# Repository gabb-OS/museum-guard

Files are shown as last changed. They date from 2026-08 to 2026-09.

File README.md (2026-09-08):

# MuseumGuard

**W3C WoT-based Smart Artwork Protection System**
*Project for the Internet of Things course (A.Y. 2025-2026) — University of Bologna (Unibo)*

---

## Project Description

**MuseumGuard** is a distributed IoT system designed for continuous monitoring and active protection of artworks in museum environments. The system combines environmental monitoring, timely threat detection (accidental impacts and theft attempts), adaptive lighting control, and interoperability based on the **W3C Web of Things (WoT)** standard.

### General Architecture

<div align="center">
  Architetture
</div>

The sensing and actuation nodes never communicate directly with each other: flow orchestration and application logic are handled by the **WoT Controller** and the **Mash-up** application. The `predictive-light` service reads history from InfluxDB and is only queried by the Mash-up to obtain the brightness estimate — it never talks directly to the devices.

---

## System Components

### 1. ESP-SEN — Sensing Node

* **Firmware:** ESP-IDF with FreeRTOS tasks dedicated to acquisition and transmission (`esp/esp-sen/sensing`).
* **Hardware:** ESP32, ambient light sensor (photoresistor on ADC), 3-axis I2C accelerometer (MPU6050), UART GPS module.
* **Features:**
  * Periodic reading of ambient light intensity and triaxial acceleration.
  * **Accidental impact** detection (sudden variation on the Z axis relative to the previous sample).
  * **Theft** detection (sustained displacement on the X axis relative to a baseline, confirmed over several consecutive samples with anti-bounce cooldown).
  * GPS tracking automatically activated after a confirmed theft, until a reset is received.
  * Dynamic runtime configuration of impact/theft thresholds, without recompilation.
* **Protocol:** CoAP (Constrained Application Protocol), UDP port `5683`.
* **Mock:** Python (`esp/esp-sen/mockup/esp_sen_mock.py`), same CoAP interface as the real firmware.

### 2. ESP-ACT — Actuation Node

* **Firmware:** ESP-IDF with FreeRTOS tasks for LED management and HTTP endpoints (`esp/esp-act/actuating`).
* **Hardware:** ESP32, PWM LED (artwork illumination, dimmable via `ledc`), dedicated digital LED for impact/theft.
* **Features:**
  * Adaptive control of artwork illumination via PWM dimming (0–100%).
  * **Impact signaling:** alarm LED blinks for 20 seconds (software timer), interruptible by a theft event.
  * **Theft signaling:** alarm LED turns on permanently until manually reset.
* **Protocol:** HTTP, port `80` on the real device (exposed as `8081` on the mock via Docker).
* **Mock:** Node.js (`esp/esp-act/mockup/server.js`, `mockup-act.js`), same HTTP interface as the real firmware.

### 3. WoT Controller (PC)

Node.js application (`wot-controller/`) that abstracts the two physical devices, exposing them as standardized **W3C WoT Things** via `@node-wot`, reachable at `http://localhost:8080`:

* **`sensor` Thing** (`/sensor`) — exposes ESP-SEN:
  * *Properties:* `ambientLight`, `accelerometer` (`{ax, ay, az}`), `thresholds` (`{impact, theft_displacement}`) — all observable.
  * *Actions:* `setImpactThreshold`, `setTheftThreshold`, `resetTracking`.
  * *Events:* `alarmEvent` — notifies `impact` / `theft` / `position`.
* **`actuator` Thing** (`/actuator`) — exposes ESP-ACT:
  * *Properties:* `artworkLedBrightness`, `alarmLightState` (`IDLE`/`IMPACT`/`THEFT`) — observable.
  * *Actions:* `regulateBrightness`, `triggerImpactBlink`, `triggerTheftAlarm`, `resetAlarmLight`.

The adapters towards the physical devices (CoAP for the sensor, HTTP for the actuator) live in `wot-controller/src/adapters/`.

### 4. Mash-up Application (PC)

Represents the logical core of the system (`mashup-app/`):

* Consumes the Things exposed by the WoT Controller (`clients/wotConsumer.js`).
* Performs periodic req/res polling of sensor + actuator and persists telemetry, events, and thresholds to **InfluxDB** (`logic/telemetryPoller.js`, `services/influxService.js`).
* Subscribes to the `alarmEvent` event in pub/sub mode and reacts to impacts/thefts by triggering the corresponding actuators and sending Telegram notifications (`logic/alarmHandler.js`).
* Queries the `predictive-light` service for the target brightness, with an explicit reactive fallback in case of error/timeout (`services/predictiveLightService.js`).
* Exposes a small internal REST API (`api/server.js`, port `3001`) used by Grafana's form panels for actions such as alarm reset and threshold updates, without Grafana needing to talk directly to the WoT Controller.

### 5. Predictive Lighting Service

Standalone Python/FastAPI microservice (`predictive-light/App.py`), containerized separately, based on a **"refit-once, serve-many"** architecture: the expensive ARIMA re-fit and the serving of predictions to the Mash-up are decoupled, so the service can respond to `/predict` with fine granularity without having to refit the model on every call.

* Every `PREDICT_INTERVAL_S` seconds (default `60`) it re-fits an **ARIMA** model (`pmdarima`) on the rolling window of `ambient_light` read from InfluxDB (`HISTORY_WINDOW_S` seconds), and in a single pass generates an **array of future forecasts** (`forecast_cache`), one every `FORECAST_STEP_S` seconds (default `1`), covering the interval up to the next refit.
* `GET /predict` **never re-fits** the model: it only computes how much time has elapsed since the last refit and returns the cache point closest to "now" — near-zero computational cost, regardless of how often the Mash-up polls the endpoint.
* Applies an **adaptive bias correction**: it maintains an EMA (`EMA_ALPHA`) over past forecast errors. Reconciliation still operates on a single reference point per refit cycle, selected at `PREDICTION_HORIZON_S` seconds after the fit (dedicated `prediction_error` measurement); that point is now extracted from the cache instead of being the sole output of the fit, but the reconciliation logic itself is unchanged.
* Exposes `GET /predict` → `{"predicted_ambient_light": <float>}` (Photoresistor target, predicted ambient light) and `GET /health` for diagnostics (also includes `forecast_cache_points` and `forecast_cache_age_s`); returns `503` until a valid fit is available, so the Mash-up falls back to the reactive rule.
* Writes both the forecasts (`predicted_light`) and the reconciliation errors (`prediction_error`) to InfluxDB, both viewable in Grafana and tagged with `system=museumguard`, consistent with the rest of the measurements written by the Mash-up.

### 6. Data Storage & Visualization

* **InfluxDB 2.7:** Time-series database for telemetry (`ambient_light`, `acceleration`, `actuator_state`), events (`impact_event`, `theft_event`, `position`), thresholds (`device_thresholds`), and predictive data (`predicted_light`, `prediction_error`). Bucket retention set via `INFLUXDB_RETENTION` (default `30d`) by `influxdb/init/01-setup.sh` on first startup.
* **Grafana:** `MuseumGuard` dashboard automatically provisioned (`grafana/dashboards/museumguard.json`) with environmental charts, impact/theft event tables, GPS map, actuator state, predicted-vs-actual light comparison, prediction error, and form panels (`volkovlabs-form-panel` plugin) for alarm reset and threshold configuration — the latter call the Mash-up API (`http://localhost:3001/api/...`) directly.

### 7. Telegram Alert Bot

`services/telegramService.js` module in the Mash-up: sends fire-and-forget text notifications to the configured chat whenever `alarmHandler.js` receives an `impact` or `theft` event. If `TELEGRAM_BOT_TOKEN`/`TELEGRAM_BOT_CHAT_ID` are not set, the bot remains disabled without blocking the rest of the system.

---

## Implemented Bonus Features

* **Configurable Detection Thresholds:** runtime updates of the impact (`thresholds/impact`) and theft (`thresholds/theft`) thresholds through the WoT Controller, without firmware recompilation, with range validated on the firmware side (`THRESHOLD_MIN`–`THRESHOLD_MAX`, 0.05–5.00 g).
* **Predictive Lighting Control:** ARIMA model with adaptive bias correction and a "refit-once, serve-many" architecture (periodic refit every `PREDICT_INTERVAL_S`, predictions served with `FORECAST_STEP_S` granularity from an in-memory cache) that estimates ambient light over the next `PREDICTION_HORIZON_S` seconds and proactively regulates the PWM LED, with automatic reactive fallback if the predictive service is unavailable.
* **Telegram Alert Bot:** instant notifications in case of emergency (impact/theft).
* **GPS:** To make the prototype more realistic, it was decided to add a GPS to provide the artwork's location in the event of theft. 

---

## Repository Structure

```text
museum-guard/
├── esp/
│   ├── esp-act/
│   │   ├── actuating/         # ESP-IDF firmware (Actuation Node)
│   │   │   └── main/          # main.c, networkConnect.c, shared.h
│   │   └── mockup/            # Node.js mock (server.js, mockup-act.js)
│   └── esp-sen/
│       ├── sensing/           # ESP-IDF firmware (Sensing Node)
│       │   └── main/
│       │       └── mylib/     # accelerometer, gps, wifi, coap_server
│       └── mockup/            # Python mock (esp_sen_mock.py)
├── wot-controller/            # W3C WoT Controller (Node.js / node-wot)
│   ├── src/
│   │   ├── adapters/          # espAct-adapter.js, espSen-adapter.js
│   │   ├── coap/              # coap-client.js
│   │   ├── things/            # espActThing.js, espSenThing.js
│   │   └── index.js
│   └── mockup/                # test scripts (testActThing.js)
├── mashup-app/                # Mash-up Application (Node.js)
│   └── src/
│       ├── api/                # server.js — internal REST API (port 3001)
│       ├── clients/             # wotConsumer.js
│       ├── logic/               # telemetryPoller.js, alarmHandler.js
│       ├── services/            # influxService.js, predictiveLightService.js, telegramService.js
│       ├── config.js
│       └── index.js
├── predictive-light/           # Predictive service (Python/FastAPI)
│   ├── App.py
│   └── requirements.txt
├── grafana/                    # Automatic provisioning and dashboard
│   ├── datasources/             # influxdb.yml
│   └── dashboards/              # dashboard.yml, museumguard.json
├── influxdb/
│   └── init/                   # 01-setup.sh — bucket retention
├── models/                     # STL files for 3D-printed cases
├── schematics/                 # Fritzing circuit diagrams (.fzz/.png)
├── docker-compose.yml           # Full environment orchestration
├── env.example                  # Environment variables template
├── LICENSE
└── README.md
```

---

## Interface Specification

### ESP-SEN (CoAP — port `5683/udp`)

| Resource | Method | Body / Payload | Description |
| --- | --- | --- | --- |
| `/light` | `GET` | — | Detected ambient light percentage (0–100) |
| `/accel` | `GET` | — | Average acceleration JSON `{"ax": float, "ay": float, "az": float}` |
| `/events` | `GET` (observable) | — | Latest event (`impact` / `theft` / `position`); notifies observers via CoAP Observe |
| `/thresholds` | `GET` | — | Current thresholds `{"impact": float, "theft_displacement": float}` |
| `/thresholds/impact` | `PUT` | text, numeric value (0.05–5.00) | Updates the impact threshold; `4.00 BAD_REQUEST` if out of range or payload invalid |
| `/thresholds/theft` | `PUT` | text, numeric value (0.05–5.00) | Updates the theft displacement threshold; same validation |
| `/reset_alarm` | `PUT` | — | Recalibrates the accelerometer baseline and stops GPS tracking |

### ESP-ACT (HTTP — port `80` on the real device / `8081` on the Docker mock)

| Endpoint | Method | Body | Description |
| --- | --- | --- | --- |
| `/` | `GET` | — | Basic health check |
| `/state` | `GET` | — | Current state `{"id", "brightness", "alarmState"}` |
| `/ambientlight` | `POST` | `{"brightness": 0-100}` | Sets the PWM brightness of the artwork LED |
| `/impact` | `POST` | — | Triggers impact signaling (20s blink) |
| `/theft` | `POST` | — | Triggers theft signaling (LED steady on) |
| `/reset` | `POST` | — | Resets the alarm state to `IDLE` |

### Internal Mash-up API (HTTP — port `3001`)

Used by Grafana (form panels) so they don't need to talk directly to the WoT Controller.

| Endpoint | Method | Body | Description |
| --- | --- | --- | --- |
| `/api/health` | `GET` | — | Health check |
| `/api/resetalarm` | `POST` | — | Invokes `resetAlarmLight` on the actuator |
| `/api/thresholds` | `GET` | — | Reads current thresholds from the sensor (pre-fills Grafana forms) |
| `/api/thresholds/impact` | `POST` | `{"value": number}` | Sets the impact threshold via the `sensor` Thing |
| `/api/thresholds/theft` | `POST` | `{"value": number}` | Sets the theft threshold via the `sensor` Thing |

### WoT Controller — Thing Descriptions (HTTP — port `8080`)

| Resource | Description |
| --- | --- |
| `/sensor` | Thing Description of the sensing node (properties, actions, events listed above) |
| `/actuator` | Thing Description of the actuation node |

### Predictive Light Service (HTTP — port `8000`, reachable only within the internal Docker network)

| Endpoint | Method | Description |
| --- | --- | --- |
| `/predict` | `GET` | `{"brightness": <float>}`, read from the forecast cache; `503` if no fit is available yet |
| `/health` | `GET` | Diagnostics: last fit, current EMA bias, forecast cache size/age |

---

## Getting Started

### Prerequisites

* **Docker** and **Docker Compose**
* **Node.js** (v18+) and **Python** (3.11+) *(only for standalone execution of the mocks, without Docker)*
* **ESP-IDF v5.x** *(only for deployment on real hardware)*
* Telegram Bot Token (obtainable via [@BotFather](https://t.me/BotFather))

---

### Running with Docker

The system supports several startup modes, selectable via **Docker Compose profiles** and an environment variables file.

#### Configuration

The repository only versions the `env.example` template; copy it according to the scenario you need (note: these names do **not** have a leading dot, unlike the more common `.env.*` convention):

```bash
cp env.example env.mock    # to work without hardware (both mocked)
cp env.example env.real    # to work with both real ESP32s
```

In the real-hardware scenario, set the device IP addresses on your LAN in `env.real`:

```env
ESP_SEN_ADDRESS=192.168.x.x
ESP_ACT_ADDRESS=192.168.x.x
```

> ⚠️ The PC running `docker compose` must be on the same WiFi network as the ESP32s — the WoT Controller reaches them as an outgoing CoAP/HTTP client, no port needs to be exposed on the ESP32 side.

For **mixed** scenarios (one real node, the other mocked), the only difference is that in `ESP_SEN_ADDRESS`/`ESP_ACT_ADDRESS` you put the mock container name for the node you want to simulate, and the real IP for the other:

```env
# example: ESP-SEN real device connected, ESP-ACT still mocked
ESP_SEN_ADDRESS=192.168.1.42
ESP_ACT_ADDRESS=esp-act-mock
```

#### Main Environment Variables

| Variable | Default | Description |
| --- | --- | --- |
| `INFLUXDB_USERNAME` / `INFLUXDB_PASSWORD` | — | InfluxDB admin credentials (initial setup) |
| `INFLUXDB_ORG` / `INFLUXDB_BUCKET` / `INFLUXDB_TOKEN` | — | InfluxDB organization, bucket, and token, shared by all services |
| `INFLUXDB_RETENTION` | `30d` | Bucket retention, applied by `01-setup.sh` |
| `GRAFANA_USER` / `GRAFANA_PASSWORD` | — | Grafana admin credentials |
| `TELEGRAM_BOT_TOKEN` / `TELEGRAM_BOT_CHAT_ID` | — | Telegram bot; if absent, alerts remain disabled |
| `ESP_SEN_ADDRESS` / `ESP_ACT_ADDRESS` | `esp-sen-mock` / `esp-act-mock` | Node hosts (mock or real IP on the LAN) |
| `COAP_PORT` / `HTTP_PORT` | — | Ports used by the WoT Controller to reach ESP-SEN/ESP-ACT |
| `TELEMETRY_POLL_MS` | `5000` | Req/res polling interval of sensor+actuator in the Mash-up |
| `MASHUP_SERVER_API_PORT` | `3001` | Port of the Mash-up's internal REST API |
| `PREDICTIVE_LIGHT_URL` | `http://predictive-light:8000` | URL of the predictive service, as seen by the Mash-up |
| `PREDICTIVE_LIGHT_TIMEOUT_MS` | `3000` | Timeout for the call to `predictive-light` before falling back to the reactive rule |
| `PREDICT_INTERVAL_S` | `60` | How often (seconds) `predictive-light` re-fits the ARIMA model and regenerates the forecast cache ("refit-once, serve-many") |
| `FORECAST_STEP_S` | `1` | Granularity (in seconds) of the forecasts served from the cache between one refit and the next; ideally aligned with `TELEMETRY_POLL_MS` |
| `PREDICTION_HORIZON_S` | `30` | Forecast horizon used for reconciliation/EMA bias (seconds into the future relative to the fit) |
| `HISTORY_WINDOW_S` | `600` | Rolling history window used for the ARIMA fit |
| `EMA_ALPHA` | `0.3` | EMA weight for the adaptive bias correction |

#### Clone and Run

```bash
git clone https://github.com/your-username/museum-guard.git
cd museum-guard
```

**With both mocks (test environment, no hardware):**
```bash
docker compose --env-file env.mock --profile mock up -d
```

**With a single mocked node** (the other real, IP address set in `env.mock`/`env.real`):
```bash
docker compose --env-file env.mock --profile mock-sen up -d   # only ESP-SEN mocked
docker compose --env-file env.mock --profile mock-act up -d   # only ESP-ACT mocked
```

**With real hardware connected (both nodes):**
```bash
docker compose --env-file env.real up -d
```
(here the mock containers do *not* start, even though they remain defined in `docker-compose.yml`, because they don't belong to the default profile)

If you'd rather not type `--env-file` every time, you can copy the chosen file to `.env` (which Compose loads automatically):
```bash
cp env.mock .env   # or env.real, depending on the scenario
docker compose --profile mock up -d          # both mocked
docker compose --profile mock-sen up -d      # only sensing mocked
docker compose up -d                         # real hardware, no profile
```

#### Check Running Services

* **Grafana:** [http://localhost:3000](http://localhost:3000) — dashboard and InfluxDB datasource already provisioned
* **InfluxDB:** [http://localhost:8086](http://localhost:8086)
* **WoT Controller:** [http://localhost:8080](http://localhost:8080) — Thing Descriptions of the exposed nodes at `/sensor` and `/actuator`
* **Mash-up API:** [http://localhost:3001/api/health](http://localhost:3001/api/health)
* **Predictive Light:** reachable only within the internal Docker network (`http://predictive-light:8000`), not exposed on the host
* **ESP-SEN Mock** *(`mock` or `mock-sen` profiles)*: `coap://localhost:5683`
* **ESP-ACT Mock** *(`mock` or `mock-act` profiles)*: [http://localhost:8081](http://localhost:8081)

#### Stopping the Services

```bash
docker compose down
```

### Standalone Execution of the Mocks (without Docker)

Useful for developing or debugging a single mock in isolation:

```bash
# Sensing mock (ESP-SEN) — Python
cd esp/esp-sen/mockup
pip install -r requirements.txt
python esp_sen_mock.py

# Actuation mock (ESP-ACT) — Node.js
cd esp/esp-act/mockup
npm install
node server.js
```

---

## License

This project is distributed under the **MIT** license. See the [LICENSE](./LICENSE) file for details.

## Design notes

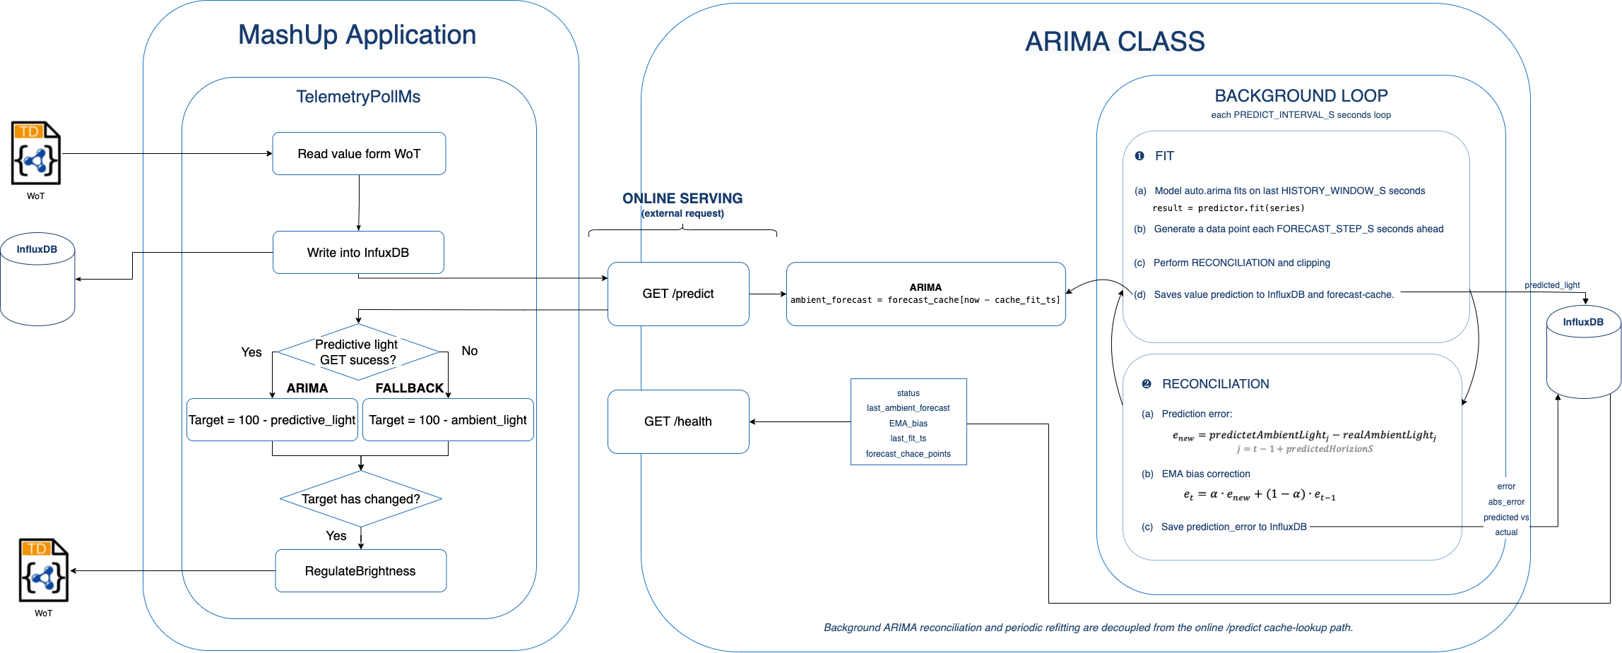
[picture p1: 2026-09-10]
schematics/predict_light.png

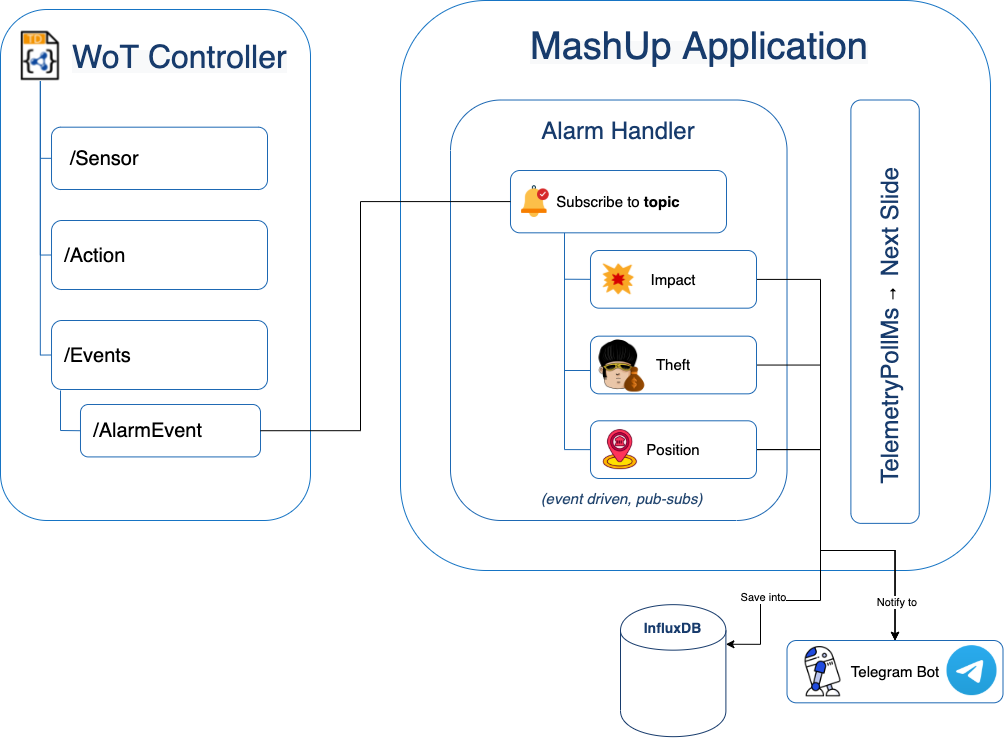
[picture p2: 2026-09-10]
schematics/alarmHandler.png

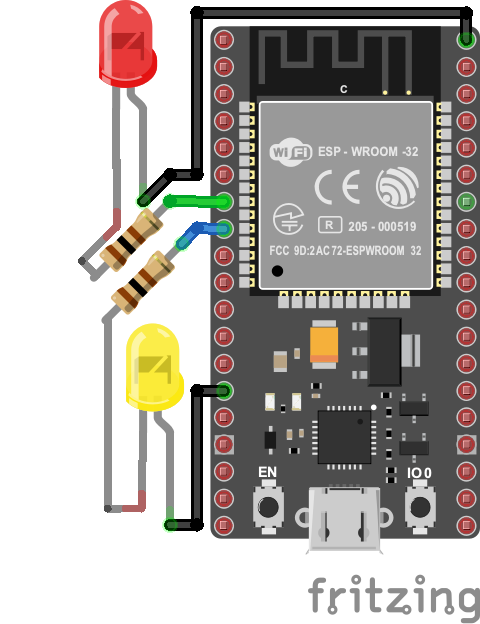
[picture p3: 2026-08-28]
schematics/actuating.png

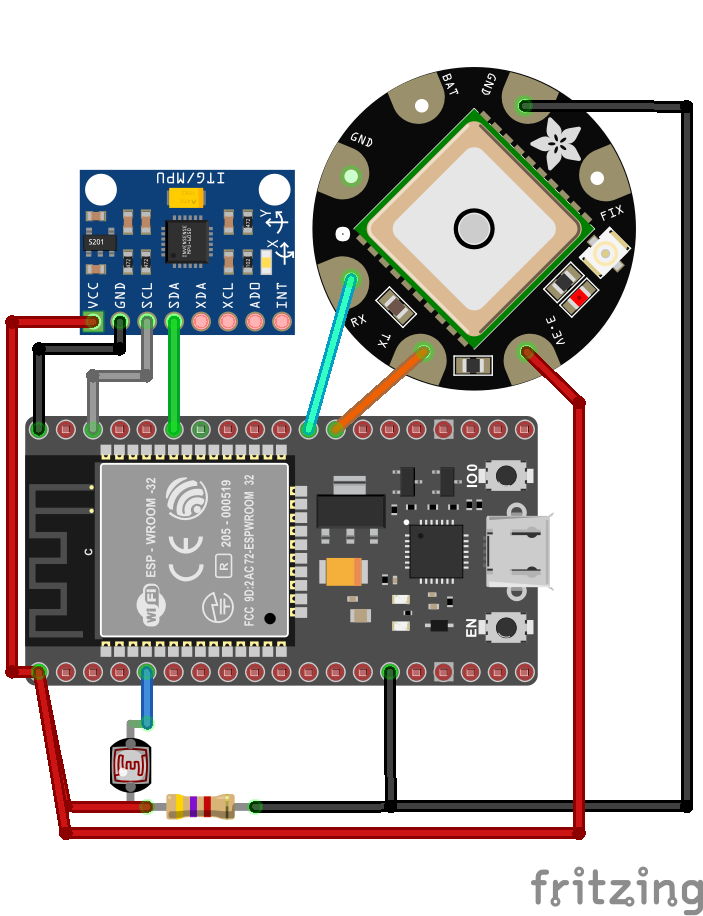
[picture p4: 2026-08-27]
schematics/sensing.png

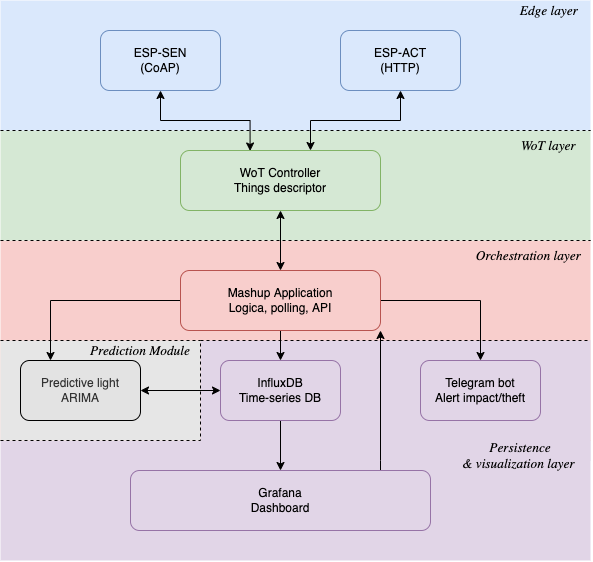
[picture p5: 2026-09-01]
schematics/Architetture.png

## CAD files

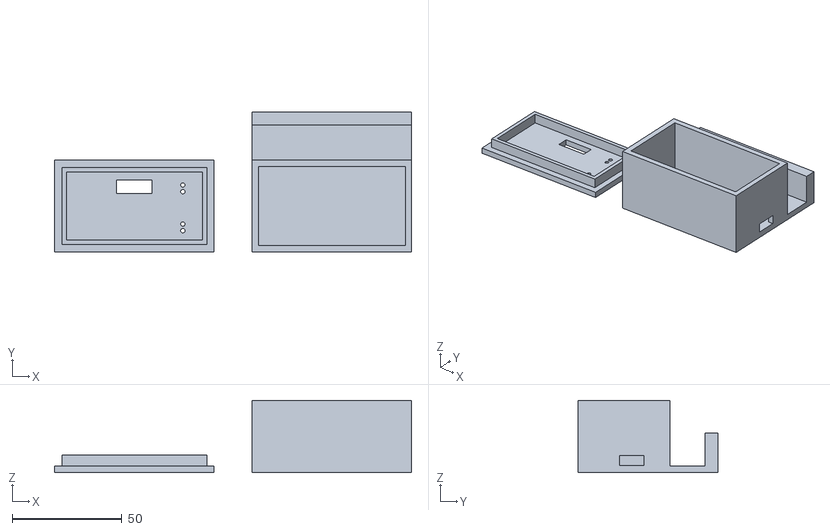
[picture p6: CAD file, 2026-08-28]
models/case actuating.stl
162.7 x 63.8 x 33.0

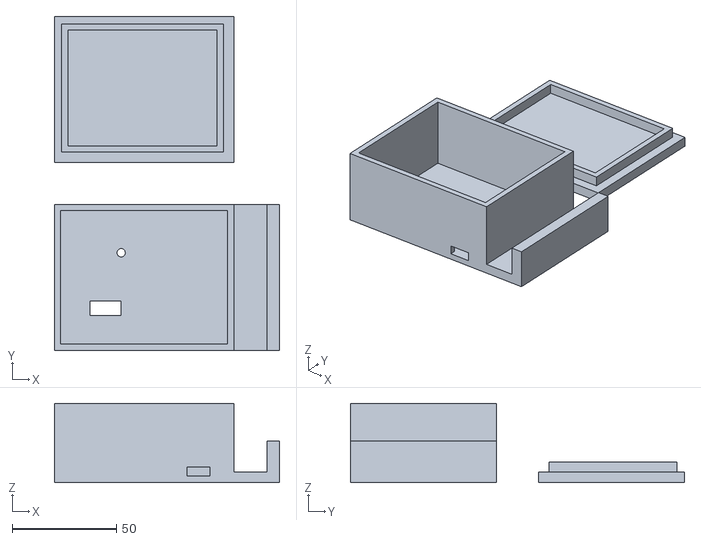
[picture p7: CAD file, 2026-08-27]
models/case sensing.stl
108.0 x 160.0 x 38.0

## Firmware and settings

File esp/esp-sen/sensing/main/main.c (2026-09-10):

#include <stdio.h>
#include <stdlib.h>
#include <string.h>
#include <math.h>
#include <coap3/coap.h>
#include "freertos/FreeRTOS.h"
#include "freertos/task.h"
#include <stdint.h>
#include "driver/gpio.h"
#include "esp_log.h"
#include "esp_timer.h"
#include "driver/adc.h"
#include "nvs_flash.h"
#include "mylib/accelerometer.h"
#include "mylib/wifi.h"
#include "mylib/coap_server.h"
#include "mylib/gps.h"

// Wifi 
#define WIFI_SSID          CONFIG_WIFI_SSID
#define WIFI_PASSWORD      CONFIG_WIFI_PASSWORD
// GPS
#define GPS_UART_NUM   UART_NUM_1
#define GPS_TX_PIN     GPIO_NUM_17
#define GPS_RX_PIN     GPIO_NUM_16
#define GPS_BAUD_RATE  9600
#define GPS_PING_INTERVAL_MS      5000   // during tracking (theft)
#define GPS_WARMUP_INTERVAL_MS    2000   // cold start, before the first fix
#define GPS_IDLE_INTERVAL_MS      10000  // idle, after the first fix, no theft

// global alert state
static bool g_tracking_active = false;
static SemaphoreHandle_t g_tracking_mutex;

// mutex dedicated to the theft detection state (baseline + counter)
static SemaphoreHandle_t g_theft_mutex;

// photoresistor stuff
#define LIGHT_SENS ADC1_CHANNEL_6
#define LIGHT_RAW_MIN             0
#define LIGHT_RAW_MAX             4095
static float g_light_percent = 0.0f;
static int g_light_raw = 0;
SemaphoreHandle_t g_light_mutex;

// accelerometer stuff
#define SDA_ACC_SENS GPIO_NUM_21
#define SCL_ACC_SENS GPIO_NUM_22
#define I2C_MASTER_NUM      I2C_NUM_0
#define I2C_MASTER_FREQ_HZ  400000
static float sum_ax = 0, sum_ay = 0, sum_az = 0;
static int sample_count = 0;
static SemaphoreHandle_t g_accel_mutex;
static float g_avg_ax = 0, g_avg_ay = 0, g_avg_az = 0; 

// runtime configurable thresholds
static float g_impact_threshold = 0.4f;
static float g_theft_displacement_threshold = 0.25f;
static SemaphoreHandle_t g_threshold_mutex;
#define THRESHOLD_MIN 0.05f
#define THRESHOLD_MAX 5.00f

// THEFT
#define THEFT_CONFIRM_SAMPLES        6
static float baseline_ax = 0;
static bool  baseline_set = false;
static int   theft_counter = 0;
#define THEFT_COOLDOWN_MS 3000
static int64_t last_theft_trigger_us = 0;

void read_light_sensor(void *pvParameters) {
    while (1) {
        int raw = adc1_get_raw(LIGHT_SENS);
        float percent;
        if (raw <= LIGHT_RAW_MIN) {
            percent = 0.0f;
        } else if (raw >= LIGHT_RAW_MAX) {
            percent = 100.0f;
        } else {
            percent = (float)(raw - LIGHT_RAW_MIN) / (LIGHT_RAW_MAX - LIGHT_RAW_MIN) * 100.0f;
        }

        xSemaphoreTake(g_light_mutex, portMAX_DELAY);
        g_light_raw = raw;
        g_light_percent = percent;
        xSemaphoreGive(g_light_mutex);
        
        xSemaphoreTake(g_tracking_mutex, portMAX_DELAY);
        bool is_tracking = g_tracking_active;
        xSemaphoreGive(g_tracking_mutex);
        ESP_LOGI("STATUS", "Luce RAW: %d | Percentuale: %.1f%% | Stato: %s", raw, percent, is_tracking ? "TRACKING" : "IDLE");
        
        vTaskDelay(pdMS_TO_TICKS(1000));
    }
}

void calibrate_theft_baseline(float ax) {
    xSemaphoreTake(g_theft_mutex, portMAX_DELAY);
    baseline_ax = ax;
    baseline_set = true;
    xSemaphoreGive(g_theft_mutex);
}

void read_accelerometer_sensor(void *pvParameters) {
    float ax = 0, ay = 0, az = 0;
    float last_ax = 0, last_ay = 0, last_az = 0;
    float diff_x, diff_y, diff_z;
    read_accel(&last_ax, &last_ay, &last_az);
    calibrate_theft_baseline(last_ax); 
    
    while (1) {
        if (read_accel(&ax, &ay, &az)) {
            diff_z = az - last_az;

            // --- IMPACT ---
            xSemaphoreTake(g_threshold_mutex, portMAX_DELAY);
            float impact_th = g_impact_threshold;
            xSemaphoreGive(g_threshold_mutex);
            
            if (fabs(diff_z) > impact_th) {
                char event_buf[64];
                int elen = snprintf(event_buf, sizeof(event_buf),
                                    "{\"type\":\"impact\",\"axis\":\"z\",\"value\":%.3f}", diff_z);
                coap_push_event(event_buf, elen);
                ESP_LOGW("EVENT", "IMPATTO rilevato (diff_z: %.3f)", diff_z);
            }
            
            // --- THEFT ---
            xSemaphoreTake(g_threshold_mutex, portMAX_DELAY);
            float theft_th = g_theft_displacement_threshold;
            xSemaphoreGive(g_threshold_mutex);
            
            xSemaphoreTake(g_theft_mutex, portMAX_DELAY);
            if (baseline_set) {
                float displacement = ax - baseline_ax;
                
                if (fabs(displacement) > theft_th) {
                    theft_counter += 2;
                    if (theft_counter > 50) theft_counter = 50;
                } else if (fabs(displacement) < (theft_th * 0.4f)) {
                    theft_counter -= 1;
                    if (theft_counter < 0) theft_counter = 0;
                }
                
                if (theft_counter >= THEFT_CONFIRM_SAMPLES) {
                    int64_t now_us = esp_timer_get_time();
                    if (now_us - last_theft_trigger_us > (int64_t)THEFT_COOLDOWN_MS * 1000) {
                        char event_buf[64];
                        int elen = snprintf(event_buf, sizeof(event_buf),
                                            "{\"type\":\"theft\",\"axis\":\"x\",\"value\":%.3f}", displacement);
                        coap_push_event(event_buf, elen);
                        
                        xSemaphoreTake(g_tracking_mutex, portMAX_DELAY);
                        g_tracking_active = true;
                        xSemaphoreGive(g_tracking_mutex);
                        last_theft_trigger_us = now_us;
                        
                        ESP_LOGE("EVENT", "FURTO confermato (spostamento: %.3f)", displacement);
                    }
                    theft_counter = 0;
                }
            }
            xSemaphoreGive(g_theft_mutex);
            
            last_ax = ax;
            last_ay = ay;
            last_az = az;
            
            xSemaphoreTake(g_accel_mutex, portMAX_DELAY);
            sum_ax += ax;
            sum_ay += ay;
            sum_az += az;
            sample_count++;
            xSemaphoreGive(g_accel_mutex);
        }
        vTaskDelay(pdMS_TO_TICKS(10));
    }
}

void accel_avg_task(void *pvParameters) {
    int print_counter = 0;
    while (1) {
        xSemaphoreTake(g_accel_mutex, portMAX_DELAY);
        if (sample_count > 0) {
            g_avg_ax = sum_ax / sample_count;
            g_avg_ay = sum_ay / sample_count;
            g_avg_az = sum_az / sample_count;
        }
        
        sum_ax = sum_ay = sum_az = 0;
        sample_count = 0;
        xSemaphoreGive(g_accel_mutex);
        
        // Print the average acceleration every 1 second (4 cycles of 250ms)
        print_counter++;
        if (print_counter >= 4) {
            ESP_LOGI("ACCEL", "Media: ax=%.3f ay=%.3f az=%.3f", g_avg_ax, g_avg_ay, g_avg_az);
            print_counter = 0;
        }
        
        vTaskDelay(pdMS_TO_TICKS(250)); 
    }
}

// --- GPS TASK  ---
void gps_ping_task(void *pvParameters) {
    bool last_tracking = false;
    bool last_has_fix = false;
    int warmup_no_fix_counter = 0;
    bool ever_had_fix = false;

    ESP_LOGI("GPS", "Task avviata. Modulo GPS in riscaldamento (warmup)...");

    while (1) {
        // 1. Check tracking status
        bool tracking;
        xSemaphoreTake(g_tracking_mutex, portMAX_DELAY);
        tracking = g_tracking_active;
        xSemaphoreGive(g_tracking_mutex);

        // Log ONLY when tracking status changes
        if (tracking != last_tracking) {
            if (tracking) {
                ESP_LOGW("GPS", ">>> TRACKING ATTIVATO (Furto rilevato) <<<");
            } else {
                ESP_LOGI("GPS", "<<< TRACKING DISATTIVATO (Reset) <<<");
            }
            last_tracking = tracking;
        }

        // 2. Read GPS
        float lat = 0.0, lon = 0.0;
        bool has_fix = read_gps(&lat, &lon);

        if (has_fix) ever_had_fix = true;

        // 3. Log ONLY when the Fix status changes (avoid spam)
        if (has_fix != last_has_fix) {
            if (has_fix) {
                ESP_LOGI("GPS", "Fix GPS ACQUISITO con successo!");
            } else {
                ESP_LOGW("GPS", "Fix GPS PERSO. Il modulo sta ricercando i satelliti...");
            }
            last_has_fix = has_fix;
        }

        // 4. Combined State-Based Actions and Logging
        if (has_fix) {
            if (tracking) {
                // Print the EXACT coordinates only if we are in theft mode
                ESP_LOGI("GPS", "Posizione (TRACKING): lat=%.6f, lon=%.6f", lat, lon);
                char event_buf[64];
                int elen = snprintf(event_buf, sizeof(event_buf),
                                    "{\"type\":\"position\",\"lat\":%.6f,\"lon\":%.6f}", lat, lon);
                coap_push_event(event_buf, elen);
            }
        } else {
            // If we are tracking and we do NOT have the fix, it is a critical error to report
            if (tracking) {
                ESP_LOGE("GPS", "CRITICO: Tracking attivo ma NESSUN FIX GPS disponibile!");
            } else {
                // In warmup, we print a reminder every 15 attempts (~30 seconds)
                // to confirm that the task is not blocked, without spamming.
                warmup_no_fix_counter++;
                if (warmup_no_fix_counter >= 15) {
                    ESP_LOGI("GPS", "Warmup: ancora in ricerca satelliti... (assicurati di essere all'aperto o vicino a una finestra)");
                    warmup_no_fix_counter = 0;
                }
            }
        }

        TickType_t interval;
        if (tracking) {
            interval = GPS_PING_INTERVAL_MS;
        } else if (!ever_had_fix) {
            interval = GPS_WARMUP_INTERVAL_MS;   // cold start, we are searching for satellite
        } else {
            interval = GPS_IDLE_INTERVAL_MS;     // we have had a fix so we can low down
        }
        vTaskDelay(pdMS_TO_TICKS(interval));
    }
}

// --- COAP HANDLERS ---

static void hnd_get_light(coap_resource_t *resource, coap_session_t *session, const coap_pdu_t *request, const coap_string_t *query, coap_pdu_t *response) {
    float value;
    xSemaphoreTake(g_light_mutex, portMAX_DELAY);
    value = g_light_percent;
    xSemaphoreGive(g_light_mutex);
    char buf[16];
    int len = snprintf(buf, sizeof(buf), "%.1f", value);
    coap_pdu_set_code(response, COAP_RESPONSE_CODE_CONTENT);
    coap_add_data(response, len, (const uint8_t *)buf);
}

static void hnd_get_accel(coap_resource_t *resource, coap_session_t *session, const coap_pdu_t *request, const coap_string_t *query, coap_pdu_t *response) {
    float ax, ay, az;
    xSemaphoreTake(g_accel_mutex, portMAX_DELAY);
    ax = g_avg_ax; ay = g_avg_ay; az = g_avg_az;
    xSemaphoreGive(g_accel_mutex);
    char buf[64];
    int len = snprintf(buf, sizeof(buf), "{\"ax\":%.3f,\"ay\":%.3f,\"az\":%.3f}", ax, ay, az);
    coap_pdu_set_code(response, COAP_RESPONSE_CODE_CONTENT);
    coap_add_data(response, len, (const uint8_t *)buf);
}

static void hnd_get_events(coap_resource_t *resource, coap_session_t *session, const coap_pdu_t *request, const coap_string_t *query, coap_pdu_t *response) {
    uint8_t buf[64];
    size_t len = coap_get_last_event(buf, sizeof(buf));
    coap_pdu_set_code(response, COAP_RESPONSE_CODE_CONTENT);
    if (len > 0) {
        coap_add_data(response, len, buf);
    }
}

static void hnd_get_thresholds(coap_resource_t *resource, coap_session_t *session, const coap_pdu_t *request, const coap_string_t *query, coap_pdu_t *response) {
    float impact, theft_disp;
    xSemaphoreTake(g_threshold_mutex, portMAX_DELAY);
    impact = g_impact_threshold;
    theft_disp = g_theft_displacement_threshold;
    xSemaphoreGive(g_threshold_mutex);
    char buf[80];
    int len = snprintf(buf, sizeof(buf), "{\"impact\":%.3f,\"theft_displacement\":%.3f}", impact, theft_disp);
    coap_pdu_set_code(response, COAP_RESPONSE_CODE_CONTENT);
    coap_add_data(response, len, (const uint8_t *)buf);
}

static void hnd_put_impact_threshold(coap_resource_t *resource, coap_session_t *session, const coap_pdu_t *request, const coap_string_t *query, coap_pdu_t *response) {
    size_t data_len = 0;
    const uint8_t *data = NULL;
    coap_get_data(request, &data_len, &data);

    ESP_LOGI("DIAG", "PUT /thresholds/impact ricevuto: data_len=%d, data='%.*s'", 
             (int)data_len, (int)data_len, data ? (const char*)data : "NULL");

    if (data == NULL || data_len == 0 || data_len > 15) {
        ESP_LOGW("DIAG", "Payload non valido (NULL, vuoto o troppo lungo)");
        coap_pdu_set_code(response, COAP_RESPONSE_CODE_BAD_REQUEST);
        return;
    }
    char buf[16];
    memcpy(buf, data, data_len);
    buf[data_len] = '\0';
    float value = strtof(buf, NULL);

    ESP_LOGI("DIAG", "Valore parsato con strtof: %.6f", value);

    if (value < THRESHOLD_MIN || value > THRESHOLD_MAX) {
        ESP_LOGW("DIAG", "Valore %.3f fuori range [%.2f, %.2f]", value, THRESHOLD_MIN, THRESHOLD_MAX);
        coap_pdu_set_code(response, COAP_RESPONSE_CODE_BAD_REQUEST);
        return;
    }
    xSemaphoreTake(g_threshold_mutex, portMAX_DELAY);
    g_impact_threshold = value;
    xSemaphoreGive(g_threshold_mutex);
    ESP_LOGI("CONFIG", "Soglia impatto aggiornata: %.3f", value);
    coap_pdu_set_code(response, COAP_RESPONSE_CODE_CHANGED);
}

static void hnd_put_theft_threshold(coap_resource_t *resource, coap_session_t *session, const coap_pdu_t *request, const coap_string_t *query, coap_pdu_t *response) {
    size_t data_len = 0;
    const uint8_t *data = NULL;
    coap_get_data(request, &data_len, &data);

    ESP_LOGI("DIAG", "PUT /thresholds/theft ricevuto: data_len=%d, data='%.*s'", 
             (int)data_len, (int)data_len, data ? (const char*)data : "NULL");

    if (data == NULL || data_len == 0 || data_len > 15) {
        ESP_LOGW("DIAG", "Payload non valido (NULL, vuoto o troppo lungo)");
        coap_pdu_set_code(response, COAP_RESPONSE_CODE_BAD_REQUEST);
        return;
    }
    char buf[16];
    memcpy(buf, data, data_len);
    buf[data_len] = '\0';
    float value = strtof(buf, NULL);

    ESP_LOGI("DIAG", "Valore parsato con strtof: %.6f", value);

    if (value < THRESHOLD_MIN || value > THRESHOLD_MAX) {
        ESP_LOGW("DIAG", "Valore %.3f fuori range [%.2f, %.2f]", value, THRESHOLD_MIN, THRESHOLD_MAX);
        coap_pdu_set_code(response, COAP_RESPONSE_CODE_BAD_REQUEST);
        return;
    }
    xSemaphoreTake(g_threshold_mutex, portMAX_DELAY);
    g_theft_displacement_threshold = value;
    xSemaphoreGive(g_threshold_mutex);
    ESP_LOGI("CONFIG", "Soglia furto aggiornata: %.3f", value);
    coap_pdu_set_code(response, COAP_RESPONSE_CODE_CHANGED);
}

static void hnd_put_reset_alarm(coap_resource_t *resource, coap_session_t *session, const coap_pdu_t *request, const coap_string_t *query, coap_pdu_t *response) {
    ESP_LOGI("DIAG", "PUT /reset_alarm ricevuto");
    xSemaphoreTake(g_tracking_mutex, portMAX_DELAY);
    g_tracking_active = false;
    xSemaphoreGive(g_tracking_mutex);
    
    xSemaphoreTake(g_theft_mutex, portMAX_DELAY);
    theft_counter = 0;
    xSemaphoreGive(g_theft_mutex);
    
    xSemaphoreTake(g_accel_mutex, portMAX_DELAY);
    float current_ax = g_avg_ax;
    xSemaphoreGive(g_accel_mutex);
    
    calibrate_theft_baseline(current_ax);
    
    ESP_LOGI("SYSTEM", "Reset allarme: tracking disattivato e baseline ricalibrata.");
    coap_pdu_set_code(response, COAP_RESPONSE_CODE_CHANGED);
}

void app_main(void){
    esp_err_t ret = nvs_flash_init();
    if (ret == ESP_ERR_NVS_NO_FREE_PAGES || ret == ESP_ERR_NVS_NEW_VERSION_FOUND) {
        ESP_ERROR_CHECK(nvs_flash_erase());
        ret = nvs_flash_init();
    }
    ESP_ERROR_CHECK(ret);
    
    wifi_init_sta(WIFI_SSID, WIFI_PASSWORD);
    
    if (!init_gps(GPS_UART_NUM, GPS_TX_PIN, GPS_RX_PIN, GPS_BAUD_RATE)) {
        ESP_LOGE("MAIN", "GPS init failed");
    }
    
    adc1_config_width(ADC_WIDTH_BIT_12);
    adc1_config_channel_atten(LIGHT_SENS, ADC_ATTEN_DB_12);
    
    if (!init_accelerometer(SDA_ACC_SENS, SCL_ACC_SENS)) {
        ESP_LOGE("MAIN", "Accelerometer init failed");
    }
    
    g_light_mutex = xSemaphoreCreateMutex();
    g_accel_mutex = xSemaphoreCreateMutex();
    g_theft_mutex = xSemaphoreCreateMutex();
    g_tracking_mutex = xSemaphoreCreateMutex();
    g_threshold_mutex = xSemaphoreCreateMutex();
    
    if (!coap_server_setup()) {
        ESP_LOGE("MAIN", "CoAP setup failed");
    }
    
    coap_register_get_resource("light", hnd_get_light);
    coap_register_get_resource("accel", hnd_get_accel); 
    coap_register_observable_resource("events", hnd_get_events);
    coap_register_put_resource("reset_alarm", hnd_put_reset_alarm);
    coap_register_get_resource("thresholds", hnd_get_thresholds);
    coap_register_put_resource("thresholds/impact", hnd_put_impact_threshold);
    coap_register_put_resource("thresholds/theft", hnd_put_theft_threshold);
    
    xTaskCreate(coap_server_task, "coap_task", 4096, NULL, 5, NULL);
    xTaskCreate(read_accelerometer_sensor, "acceleromete_task", 4096, NULL, 5, NULL);
    xTaskCreate(read_light_sensor, "light_task", 2048, NULL, 4, NULL);
    xTaskCreate(gps_ping_task, "gps_task", 4096, NULL, 4, NULL);
    xTaskCreate(accel_avg_task, "accel_avg_task", 2048, NULL, 3, NULL);
}

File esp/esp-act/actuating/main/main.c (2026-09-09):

#include <stdio.h>
#include "esp_random.h"
#include "esp_log.h"
#include "driver/gpio.h"
#include "driver/ledc.h"
#include "nvs_flash.h"
#include "freertos/FreeRTOS.h"
#include "freertos/task.h"
#include "freertos/timers.h"
#include <math.h>
#include "shared.h"

static const char *E_TAG = "MAIN";

TaskHandle_t ambientLightTaskHandle = NULL;
TaskHandle_t ledManagerTaskHandle = NULL;
TaskHandle_t impactTaskHandle = NULL;
TaskHandle_t theftTaskHandle = NULL;
TaskHandle_t resetTaskHandle = NULL;

TimerHandle_t impactTimer = NULL;

static httpd_handle_t server = NULL;

#define CMD_BIT_RESET  (1 << 0)     // Bit 0: 0001
#define CMD_BIT_THEFT  (1 << 1)     // Bit 1: 0010
#define CMD_BIT_IMPACT (1 << 2)     // Bit 2: 0100
#define CMD_BIT_TIMEOUT (1 << 3)    // Bit 2: 1000

SemaphoreHandle_t ambientLightMutex = NULL;
SemaphoreHandle_t alarmLightStateMutex = NULL;
static int g_currentBrightness = 0;
static alarm_state_t g_alarmState = STATE_IDLE;

void taskAlarmLedManager(void *pvParameters);
void impactTimerCallback(TimerHandle_t xTimer);

 
/* ---------------- State accessors thread-safe ---------------- */
int get_current_brightness(void)
{
    int value;
    xSemaphoreTake(ambientLightMutex, portMAX_DELAY);
    value = g_currentBrightness;
    xSemaphoreGive(ambientLightMutex);
    return value;
}
 
alarm_state_t get_current_alarm_state(void)
{
    alarm_state_t value;
    xSemaphoreTake(alarmLightStateMutex, portMAX_DELAY);
    value = g_alarmState;
    xSemaphoreGive(alarmLightStateMutex);
    return value;
}
 
const char* alarm_state_to_string(alarm_state_t state)
{
    switch (state) {
        case STATE_IMPACT: return "IMPACT";
        case STATE_THEFT:  return "THEFT";
        case STATE_IDLE:
        default:           return "IDLE";
    }
}


/************* Main *************/
void app_main(void)
{
    /* Network/webserver initialization*/
    esp_err_t ret = nvs_flash_init();
    if (ret == ESP_ERR_NVS_NO_FREE_PAGES || ret == ESP_ERR_NVS_NEW_VERSION_FOUND) {
        ESP_ERROR_CHECK(nvs_flash_erase());
        ret = nvs_flash_init();
    }

    ESP_ERROR_CHECK(ret);
    wifi_init_sta();

    server = start_webserver();
    if (server == NULL) {
        ESP_LOGE(E_TAG, "Server start failed");
    }

    /* Initialization */
    gpio_set_direction(LED_THEFT_IMPACT_PIN, GPIO_MODE_OUTPUT);
    gpio_set_level(LED_THEFT_IMPACT_PIN, 0);

    gpio_set_direction(LED_AMBIENT_PIN, GPIO_MODE_OUTPUT);

    ambientLightMutex = xSemaphoreCreateMutex();
    alarmLightStateMutex = xSemaphoreCreateMutex();

    impactTimer = xTimerCreate(
        "ImpactTmr",
        pdMS_TO_TICKS(20000),
        pdFALSE,
        (void *)0,
        impactTimerCallback
    );

    ledc_timer_config_t timer_conf = {
        .speed_mode      = LEDC_LOW_SPEED_MODE,
        .timer_num       = LEDC_TIMER_0,
        .duty_resolution = LEDC_TIMER_8_BIT,   // 0-255
        .freq_hz         = 5000,
        .clk_cfg         = LEDC_AUTO_CLK
    };
    ledc_timer_config(&timer_conf);
 
    ledc_channel_config_t channel_conf = {
        .gpio_num   = LED_AMBIENT_PIN,
        .speed_mode = LEDC_LOW_SPEED_MODE,
        .channel    = LEDC_CHANNEL_0,
        .timer_sel  = LEDC_TIMER_0,
        .duty       = 0,
        .hpoint     = 0
    };
    ledc_channel_config(&channel_conf);


    /* Task Creation */
    xTaskCreate(taskAmbientLight, "Ambiental Light", 2048, NULL, 1, &ambientLightTaskHandle);
    xTaskCreate(taskAlarmLedManager, "Alarm LED Mgr", 2048, NULL, 5, &ledManagerTaskHandle);
    xTaskCreate(taskImpactLight, "Impact Warning", 2048, NULL, 3, &impactTaskHandle);
    xTaskCreate(taskTheftLight, "Theft Warning", 2048, NULL, 4, &theftTaskHandle);
    xTaskCreate(taskResetLight, "Lights reset", 2048, NULL, 4, &resetTaskHandle);
    
    xTaskNotify(ambientLightTaskHandle, 30, eSetValueWithOverwrite);
}

// Normalizes value between [0,100] in ambientLight_post_handler
void taskAmbientLight(void *pvParameters){
    uint32_t brightness;

    while(1){
        xTaskNotifyWait(0x00, 0xFFFFFFFF, &brightness, portMAX_DELAY);
        ESP_LOGI("LIGHT", "Artwork illumination change event received! (Raw: %lu%%)", brightness);

        uint32_t duty = 0;

        if (brightness == 0) {
            duty = 0; // Turned off completely only if explicitly requested
        } else {
            // 1. We map the range 1-100 to 0.0-1.0 for the gamma curve
            float normalized = (brightness - 1) / 99.0f;
            float gamma_corrected = powf(normalized, 2.2f);
            
            // 2. Set a minimum duty cycle threshold
            // This prevents the LED from turning off below 15% input.
            uint32_t min_duty = 15; 
            
            // 3. We rescale the gamma curve result between min_duty and 255
            duty = min_duty + (uint32_t)(gamma_corrected * (255.0f - min_duty));
        }

        ledc_set_duty(LEDC_LOW_SPEED_MODE, LEDC_CHANNEL_0, duty);
        ledc_update_duty(LEDC_LOW_SPEED_MODE, LEDC_CHANNEL_0);

        xSemaphoreTake(ambientLightMutex, portMAX_DELAY);
        g_currentBrightness = brightness;
        xSemaphoreGive(ambientLightMutex);
    }
}
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

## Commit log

2026-08-11 preparation for the warning light Reset function
    [main.c]
2026-08-16 gps+wifi+acceleremotro+coap
    sono tante 8 ore di treno
2026-08-17 fix trashold + logica robista per la detection con timer
    [main.c]
2026-08-19 Add actuator getState management and HTTP state endpoint
2026-08-21 refactor: update actuator base URL configuration
2026-08-21 feat: in mashup added event driven alarm handler + telemetry polling for both sensor and actuator
2026-08-24 fix axes + ip
    [main.c]
2026-08-25 fix mock + partial prediction
    [main.c]
2026-08-27 schematics + case stl
    [actuating.fzz, case actuating.stl, case sensing.stl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]
2026-08-27 readme + fix luce + missing call per resettare il traking
2026-08-28 fix light percentage
    [actuating.fzz, case actuating.stl]
2026-08-29 Revise architecture diagram in README
    Updated architecture diagram to reflect communication flow between components.
2026-09-05 predictive-light: disaccoppia refit ARIMA da granularità delle predizioni
    - Introduce architettura "refit-once, serve-many": ARIMA viene rifittato
    ogni PREDICT_INTERVAL_S (default alzato da 5s a 60s) invece che ad ogni
    chiamata a /predict.
    - Ad ogni refit viene generato un array di previsioni future (forecast_cache),
    una ogni FORECAST_STEP_S secondi (nuovo parametro, default 1s), che copre
    l'intervallo fino al prossimo refit.
    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
2026-09-09 Fix function declaration for taskAlarmLedManager in main.c
    [main.c]
2026-09-10 mabe fix acruating overload + gps more accurate string parsing
    [gps.c]
